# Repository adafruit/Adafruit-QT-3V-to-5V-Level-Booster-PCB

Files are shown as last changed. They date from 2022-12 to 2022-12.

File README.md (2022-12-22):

## Adafruit QT 3V to 5V Level Booster Breakout - STEMMA QT / Qwiic PCB

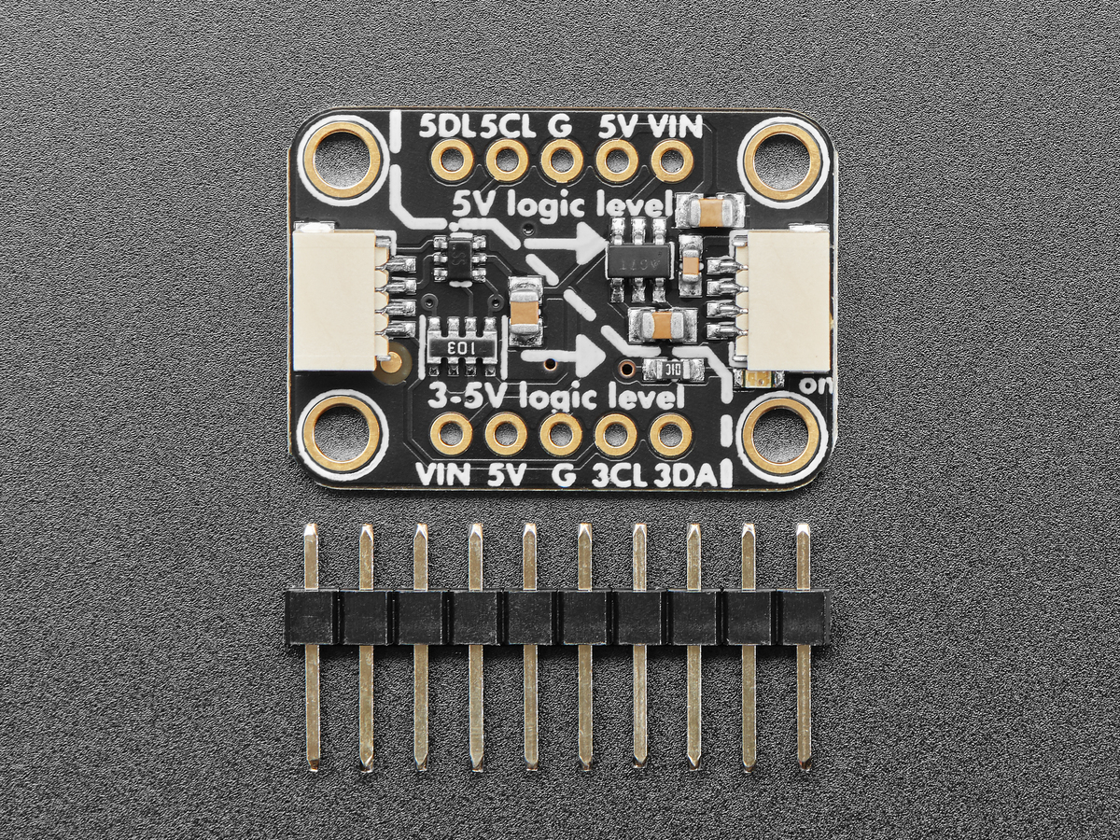
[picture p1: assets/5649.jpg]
<a href="http://www.adafruit.com/products/5649"><br/>
Click here to purchase one from the Adafruit shop</a>

PCB files for the Adafruit QT 3V to 5V Level Booster Breakout - STEMMA QT. 

Format is EagleCAD schematic and board layout
* https://www.adafruit.com/product/5649

### Description

If you're looking to use the Qwiic / Stemma QT standard for your next project - but you're using a sensor or device that requires 5V power or logic, this board is designed for you! It will let you use the 3V power and logic from your Raspberry Pi, or ARM Cortex microcontroller, and boost/shift it up to 5V for use with older or high-power devices that aren't happy with only 3V.

These days, almost every microcontroller / microcomputer board has 3V power and logic: ESP32 series, ATSAMD chips, RP2040 boards, micro:bits, etc! But we still see sensors and devices here and there that really want 5V power or logic. Like this Sensirion SEN54 which has a small motor with 5V power requirements.

On one side of this board is 3V power and logic level inputs. In the middle is a 5V charge-pump boosting regulator that can provide 100mA continuous (250mA peak) plus level shifting circuitry. On the opposite side is the same I2C traffic but now safely shifted up to 5V. If you happen to be using a board that wants 5V power, but 3V logic I2C, there's a solder jumper on the back you can cut/solder to set the output logic level to unshifted 3V.

It's simple but very effective! You also get breadboard breakout pins for breadboard usage so it can also be used as a QT-to-perfboard adapter. If you need something that does 5V to 3V down-conversion, we have that in the shop as well.

The STEMMA QT connectors on either side are compatible with the  I2C connectors. This allows you to make solderless connections between your development board and the QT Shifter or to chain it with a wide range of other sensors and accessories using a compatible cable. QT Cable is not included, but we have a variety in the shop. 

### License

Adafruit invests time and resources providing this open source design, please support Adafruit and open-source hardware by purchasing products from [Adafruit](https://www.adafruit.com)!

Designed by Limor Fried/Ladyada for Adafruit Industries.

Creative Commons Attribution/Share-Alike, all text above must be included in any redistribution. 
See license.txt for additional details.

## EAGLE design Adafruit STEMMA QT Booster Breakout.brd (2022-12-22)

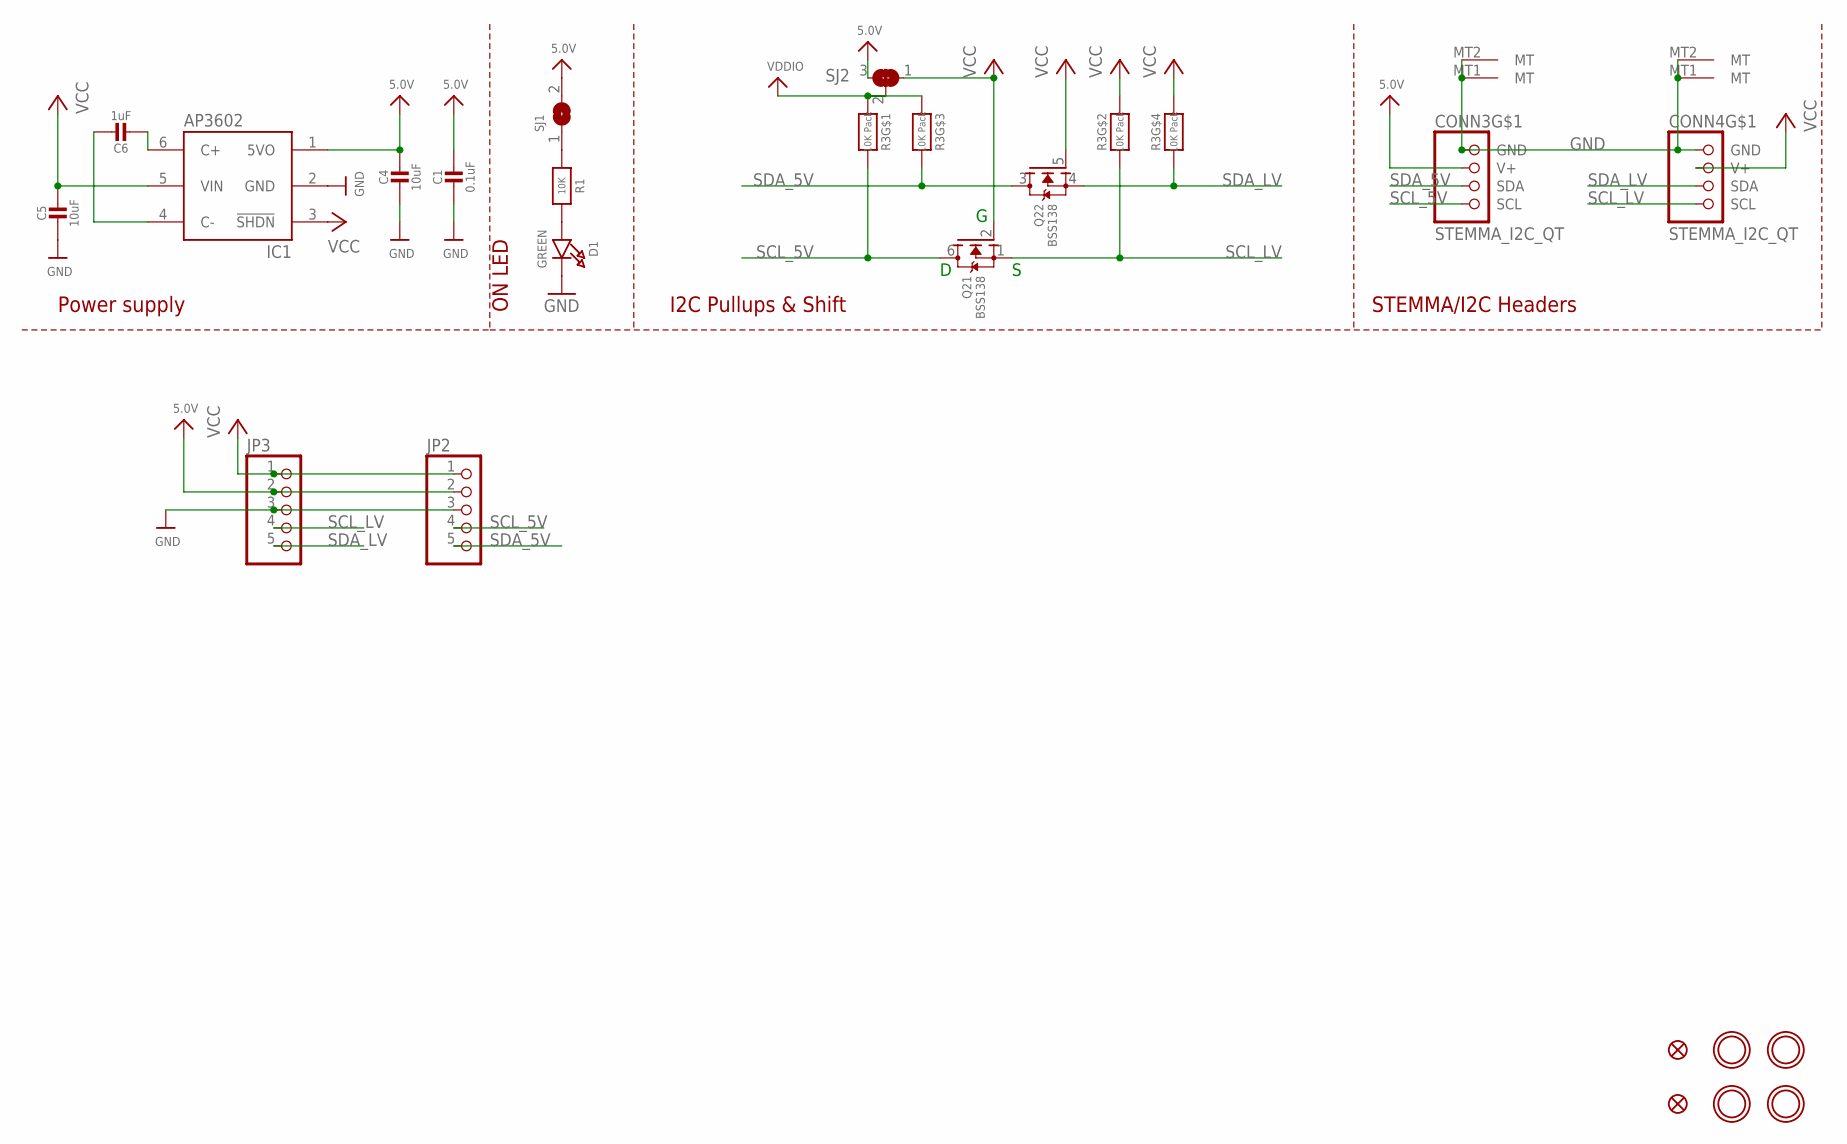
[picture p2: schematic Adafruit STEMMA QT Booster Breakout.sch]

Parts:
C1: 0.1uF; 0603-NO
C4, C5: 10uF; 0805-NO
C6: 1uF; 0805-NO
CONN3, CONN4: STEMMA_I2C_QT; JST_SH4
D1: GREEN; CHIPLED_0603_NOOUTLINE
FID3, FID4: FIDUCIAL_1MM
IC1: AP3602/RT9361; SOT23-6
JP2, JP3: HEADER-1X576MIL; 1X05_ROUND_76
Q2: BSS138; SOT363
R1: 10K; 0603-NO
R3: 10K Pack; RESPACK_4X0603
SJ1: SOLDERJUMPERCLOSED; SOLDERJUMPER_CLOSEDWIRE
SJ2: SOLDERJUMPER_2WAY; SOLDERJUMPER_2WAY_OPEN_NOPASTE
U$1, U$17, U$19, U$21: MOUNTINGHOLE2.5; MOUNTINGHOLE_2.5_PLATED

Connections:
5.0V: C1.1, C4.1, CONN3.2 (V+), IC1.1 (5VO), JP2.2, JP3.2, SJ1.2, SJ2.3
GND: C1.2, C4.2, C5.2, CONN3.1 (GND), CONN3.MT1 (MT), CONN3.MT2 (MT), CONN4.1 (GND), CONN4.MT1 (MT), CONN4.MT2 (MT), D1.C, IC1.2 (GND), JP2.3, JP3.3
unnamed: D1.A, R1.2
unnamed: R1.1, SJ1.1
unnamed: C6.2, IC1.6 (C+)
unnamed: C6.1, IC1.4 (C-)
SCL_5V: CONN3.4 (SCL), JP2.4, Q2.6 (D), R3.8 (2)
SCL_LV: CONN4.4 (SCL), JP3.4, Q2.1 (S), R3.7 (2)
SDA_5V: CONN3.3 (SDA), JP2.5, Q2.3 (D), R3.6 (2)
SDA_LV: CONN4.3 (SDA), JP3.5, Q2.4 (S), R3.5 (2)
VCC: C5.1, CONN4.2 (V+), IC1.3 (!SHDN), IC1.5 (VIN), JP2.1, JP3.1, Q2.2 (G), Q2.5 (G), R3.2 (1), R3.4 (1), SJ2.1
VDDIO: R3.1, R3.3 (1), SJ2.2

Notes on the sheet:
I2C Pullups & Shift
STEMMA/I2C Headers
ON LED
Power supply

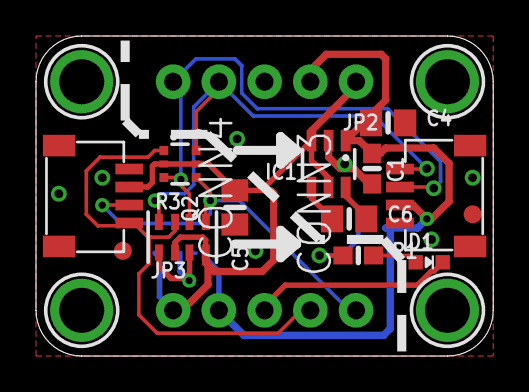
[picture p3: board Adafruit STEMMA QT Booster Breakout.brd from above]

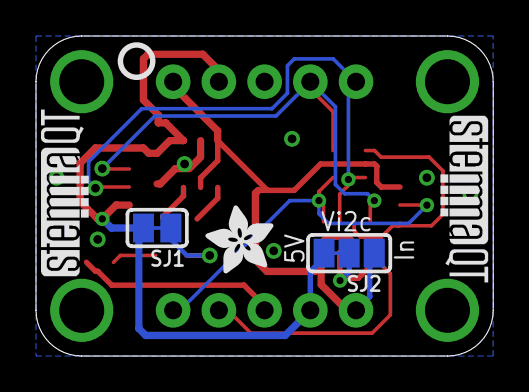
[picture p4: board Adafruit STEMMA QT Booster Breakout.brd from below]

Board: 2 copper layers, 25.4 x 17.8 mm, 40 parts (8 on the bottom side), 12 nets.

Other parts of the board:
PLABEL0: PLABEL0
PLABEL1: PLABEL1
PLABEL2: PLABEL2
PLABEL3: PLABEL3
PLABEL4: PLABEL4
PLABEL5: PLABEL5
PLABEL6: PLABEL6
PLABEL7: PLABEL7
PLABEL8: PLABEL8
PLABEL9: PLABEL9
PLABEL10: PLABEL10
PLABEL11: PLABEL11
PLABEL12: PLABEL12
PLABEL13: PLABEL13
PLABEL14: PLABEL14
U$2: ADAFRUIT_3.5MM
U$25: PCBFEAT-REV-040
U$30, U$31: STEMMAQT

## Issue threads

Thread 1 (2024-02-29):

SDA not goingto 0V during I2C stop time.

ghelbig, 2024-02-29:
Buffer is connected between a 3.3V processor (LPC55S69) and a 5.0V device (MA12070).  The only connections to SDA and SCL on the 5V side of the buffer are the chip and 5k1 pull-ups.  The pull-ups are powered by the buffer (the red lead on the 5V side).

During the stop time the SDA line does not get to 0 - it is at about 0.8 volts.

This is an I2C byte write - I2C, reg, data.  Top trace is SCL, lower is SDA:

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

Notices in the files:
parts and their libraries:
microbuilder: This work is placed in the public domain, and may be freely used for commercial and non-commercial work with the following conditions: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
